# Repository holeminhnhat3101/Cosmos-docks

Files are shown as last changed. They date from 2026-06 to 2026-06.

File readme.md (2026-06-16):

# Cosmos Docks

Cosmos Docks is a custom 9-key macropad designed from scratch for Hack Club Stardance. It includes a custom PCB, a fully 3D-printable case, one rotary encoder, an OLED display, and SK6812MINI-E addressable RGB LEDs.

The design is built around the Seeed XIAO RP2040 and uses QMK firmware.

## Features

- 9 MX-style mechanical switches
- 1 EC11 rotary encoder
- 0.91 inch 128×32 I2C OLED display
- 13 SK6812MINI-E addressable RGB LEDs
- Seeed XIAO RP2040 microcontroller
- Custom 2-layer PCB designed in KiCad
- Fully 3D-printable top and bottom case
- QMK firmware with OLED, encoder, and RGB Matrix support
- M3 screws and heat-set inserts for case assembly

### PCB design preview
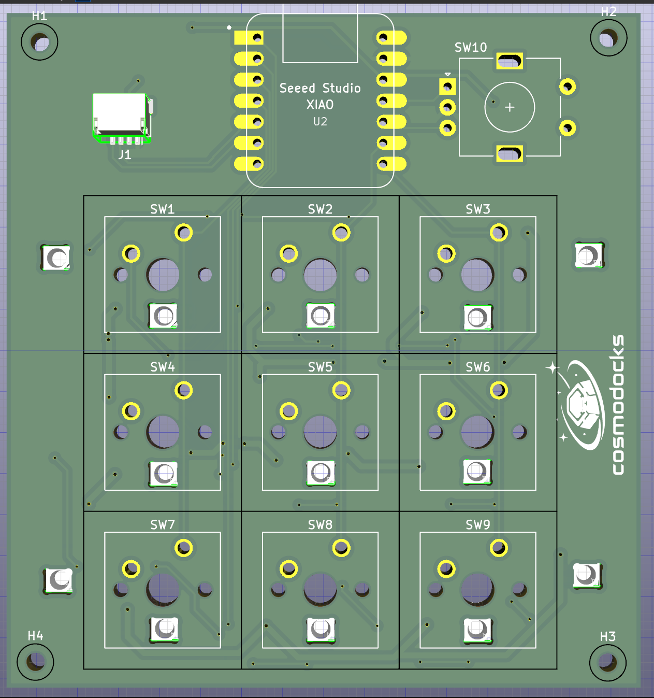
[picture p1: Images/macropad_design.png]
Design preview of Cosmos Docks


### PCB Layout
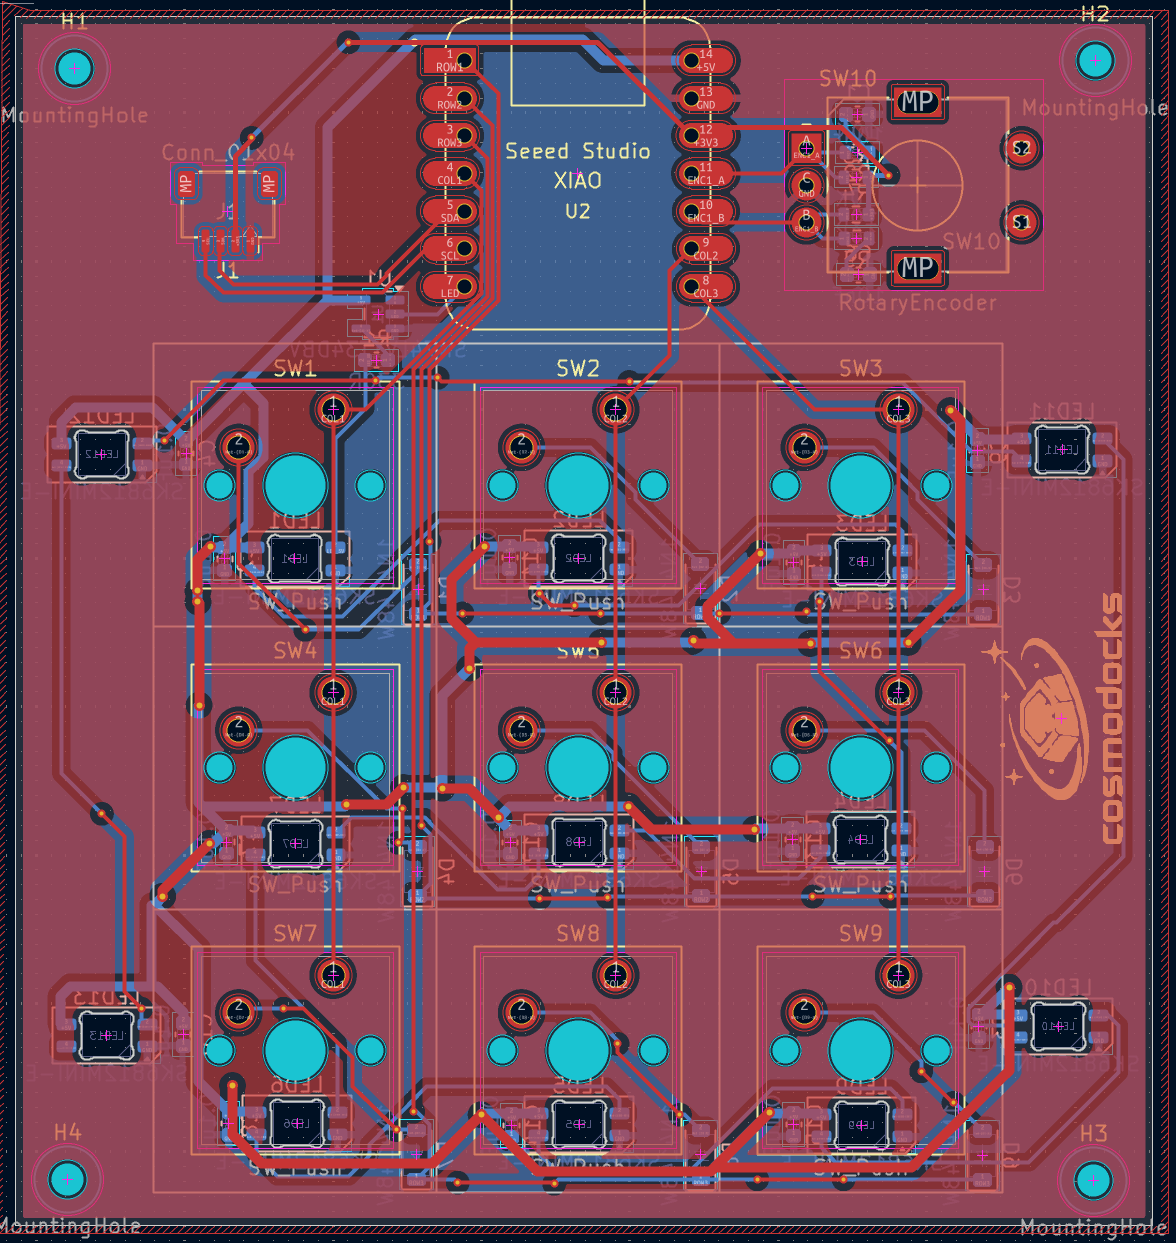
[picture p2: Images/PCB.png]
PCB layout of Cosmos Docks


### Schematic
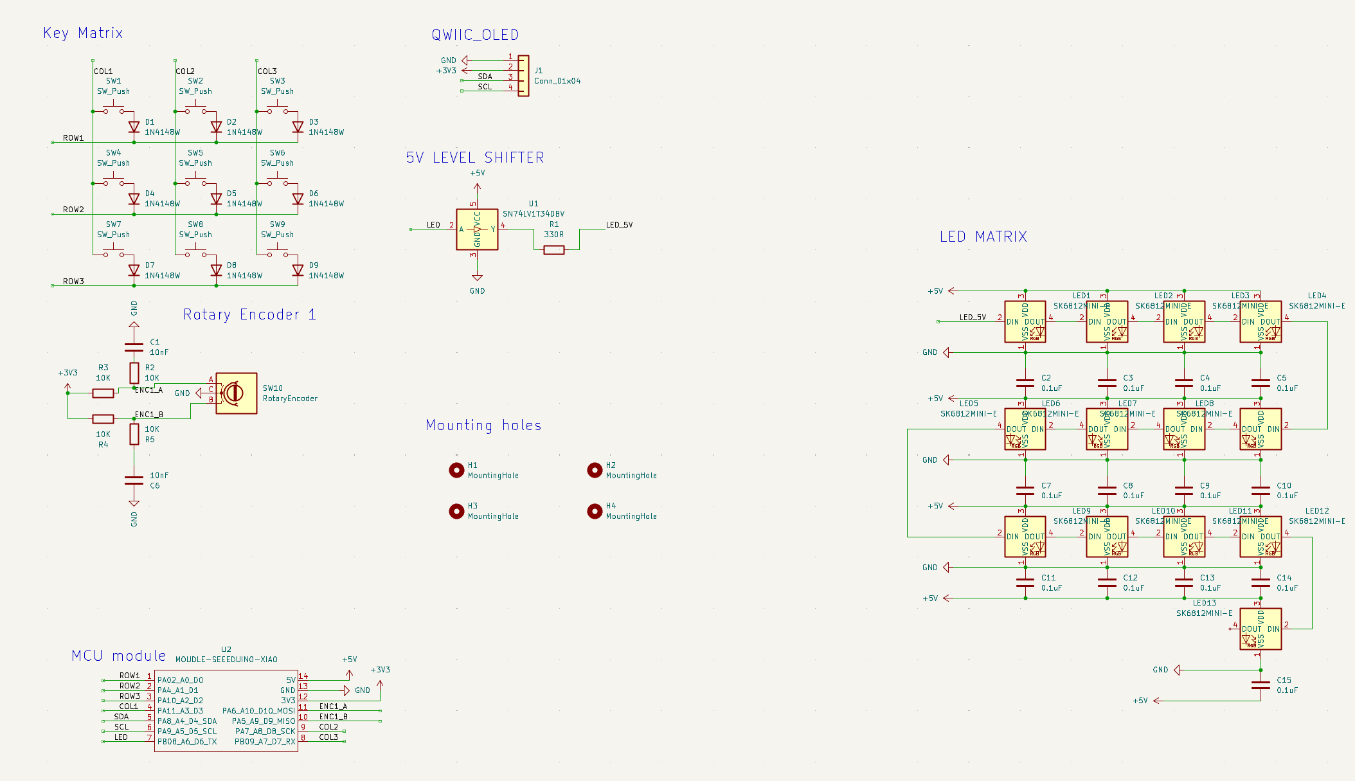
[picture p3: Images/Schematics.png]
Schematic of Cosmos Docks


### 3D Assembly
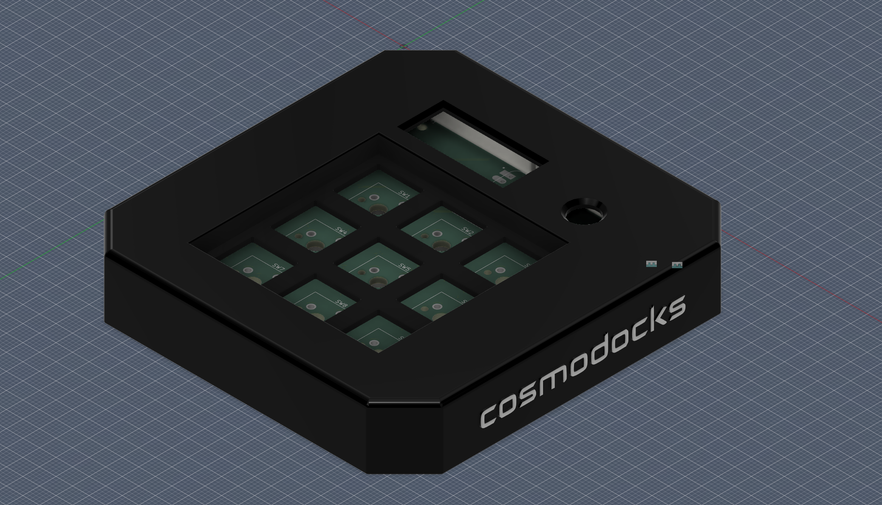
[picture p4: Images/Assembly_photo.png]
3D assembly photo of Cosmos Docks


## Bill of Materials

| Component | Quantity | Notes |
| --- | ---: | --- |
| Seeed XIAO RP2040 | 1 | Main microcontroller |
| MX-style mechanical switches | 9 | Main key switches |
| Blank DSA keycaps | 9 | Keycaps for the switches |
| 1N4148W SMD diodes | 9 | One diode per switch |
| EC11 rotary encoder | 1 | 20 mm D-shaft rotary encoder |
| 0.91 inch 128×32 I2C OLED display | 1 | OLED screen connected through I2C |
| JST-SH 4-pin connector | 1 | QWIIC/I2C OLED connector, SM04B-SRSS-TB, 1.00 mm pitch, horizontal |
| SK6812MINI-E RGB LEDs | 13 | Addressable RGB LEDs |
| 0.1 µF capacitors | 13 | One decoupling capacitor per RGB LED |
| 10 nF capacitors | 2 | Rotary encoder debounce/filtering capacitors |
| SN74LV1T34DBV level shifter | 1 | Shifts LED data from 3.3 V to 5 V |
| 330 Ω resistor | 1 | LED data line resistor |
| 10 kΩ resistors | 4 | Rotary encoder pull-up/pull-down resistors |
| M3×16 mm screws | 4 | Used to connect the top and bottom case |
| M3 heat-set inserts | 4 | Installed into the 3D-printed case |
| Custom PCB | 1 | 2-layer PCB designed in KiCad |
| 3D-printed top case | 1 | Top enclosure / switch plate |
| 3D-printed bottom case | 1 | Bottom enclosure |
| Soldering equipment | 1 | I don't have one |

## Firmware

The firmware is written using QMK. It includes support for:

- 3×3 key matrix
- Rotary encoder
- OLED display
- RGB Matrix lighting for SK6812MINI-E LEDs

The compiled firmware file is included in the production folder as:

firmware.uf2

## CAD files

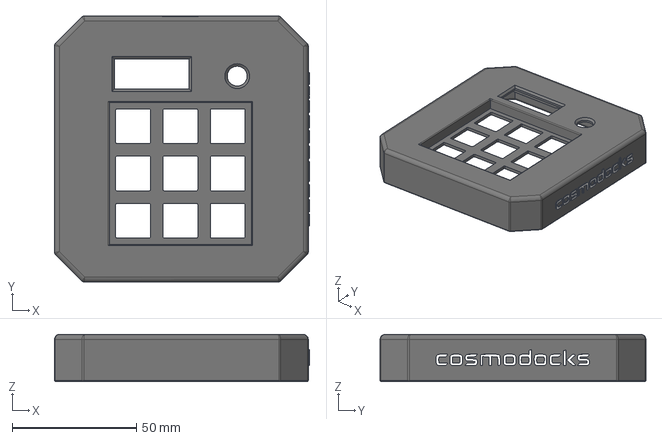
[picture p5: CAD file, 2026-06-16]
production/Top Case.step
102.7 x 107.1 x 19.0 mm

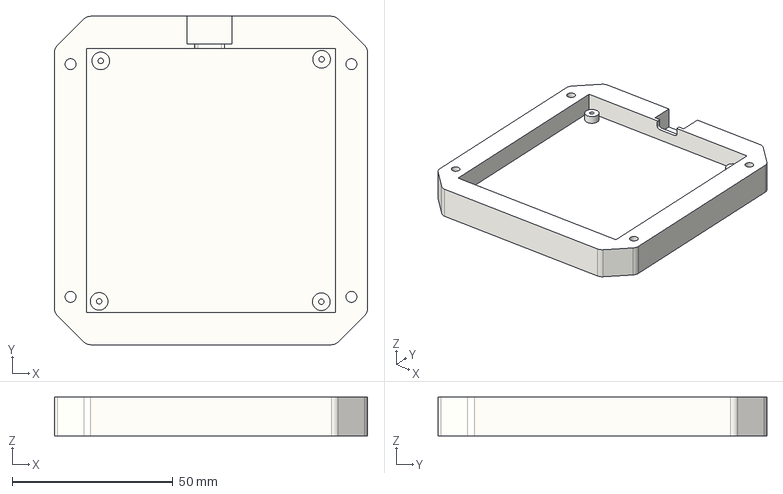
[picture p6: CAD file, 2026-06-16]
production/Bottom Case.step
97.4 x 102.2 x 12.1 mm

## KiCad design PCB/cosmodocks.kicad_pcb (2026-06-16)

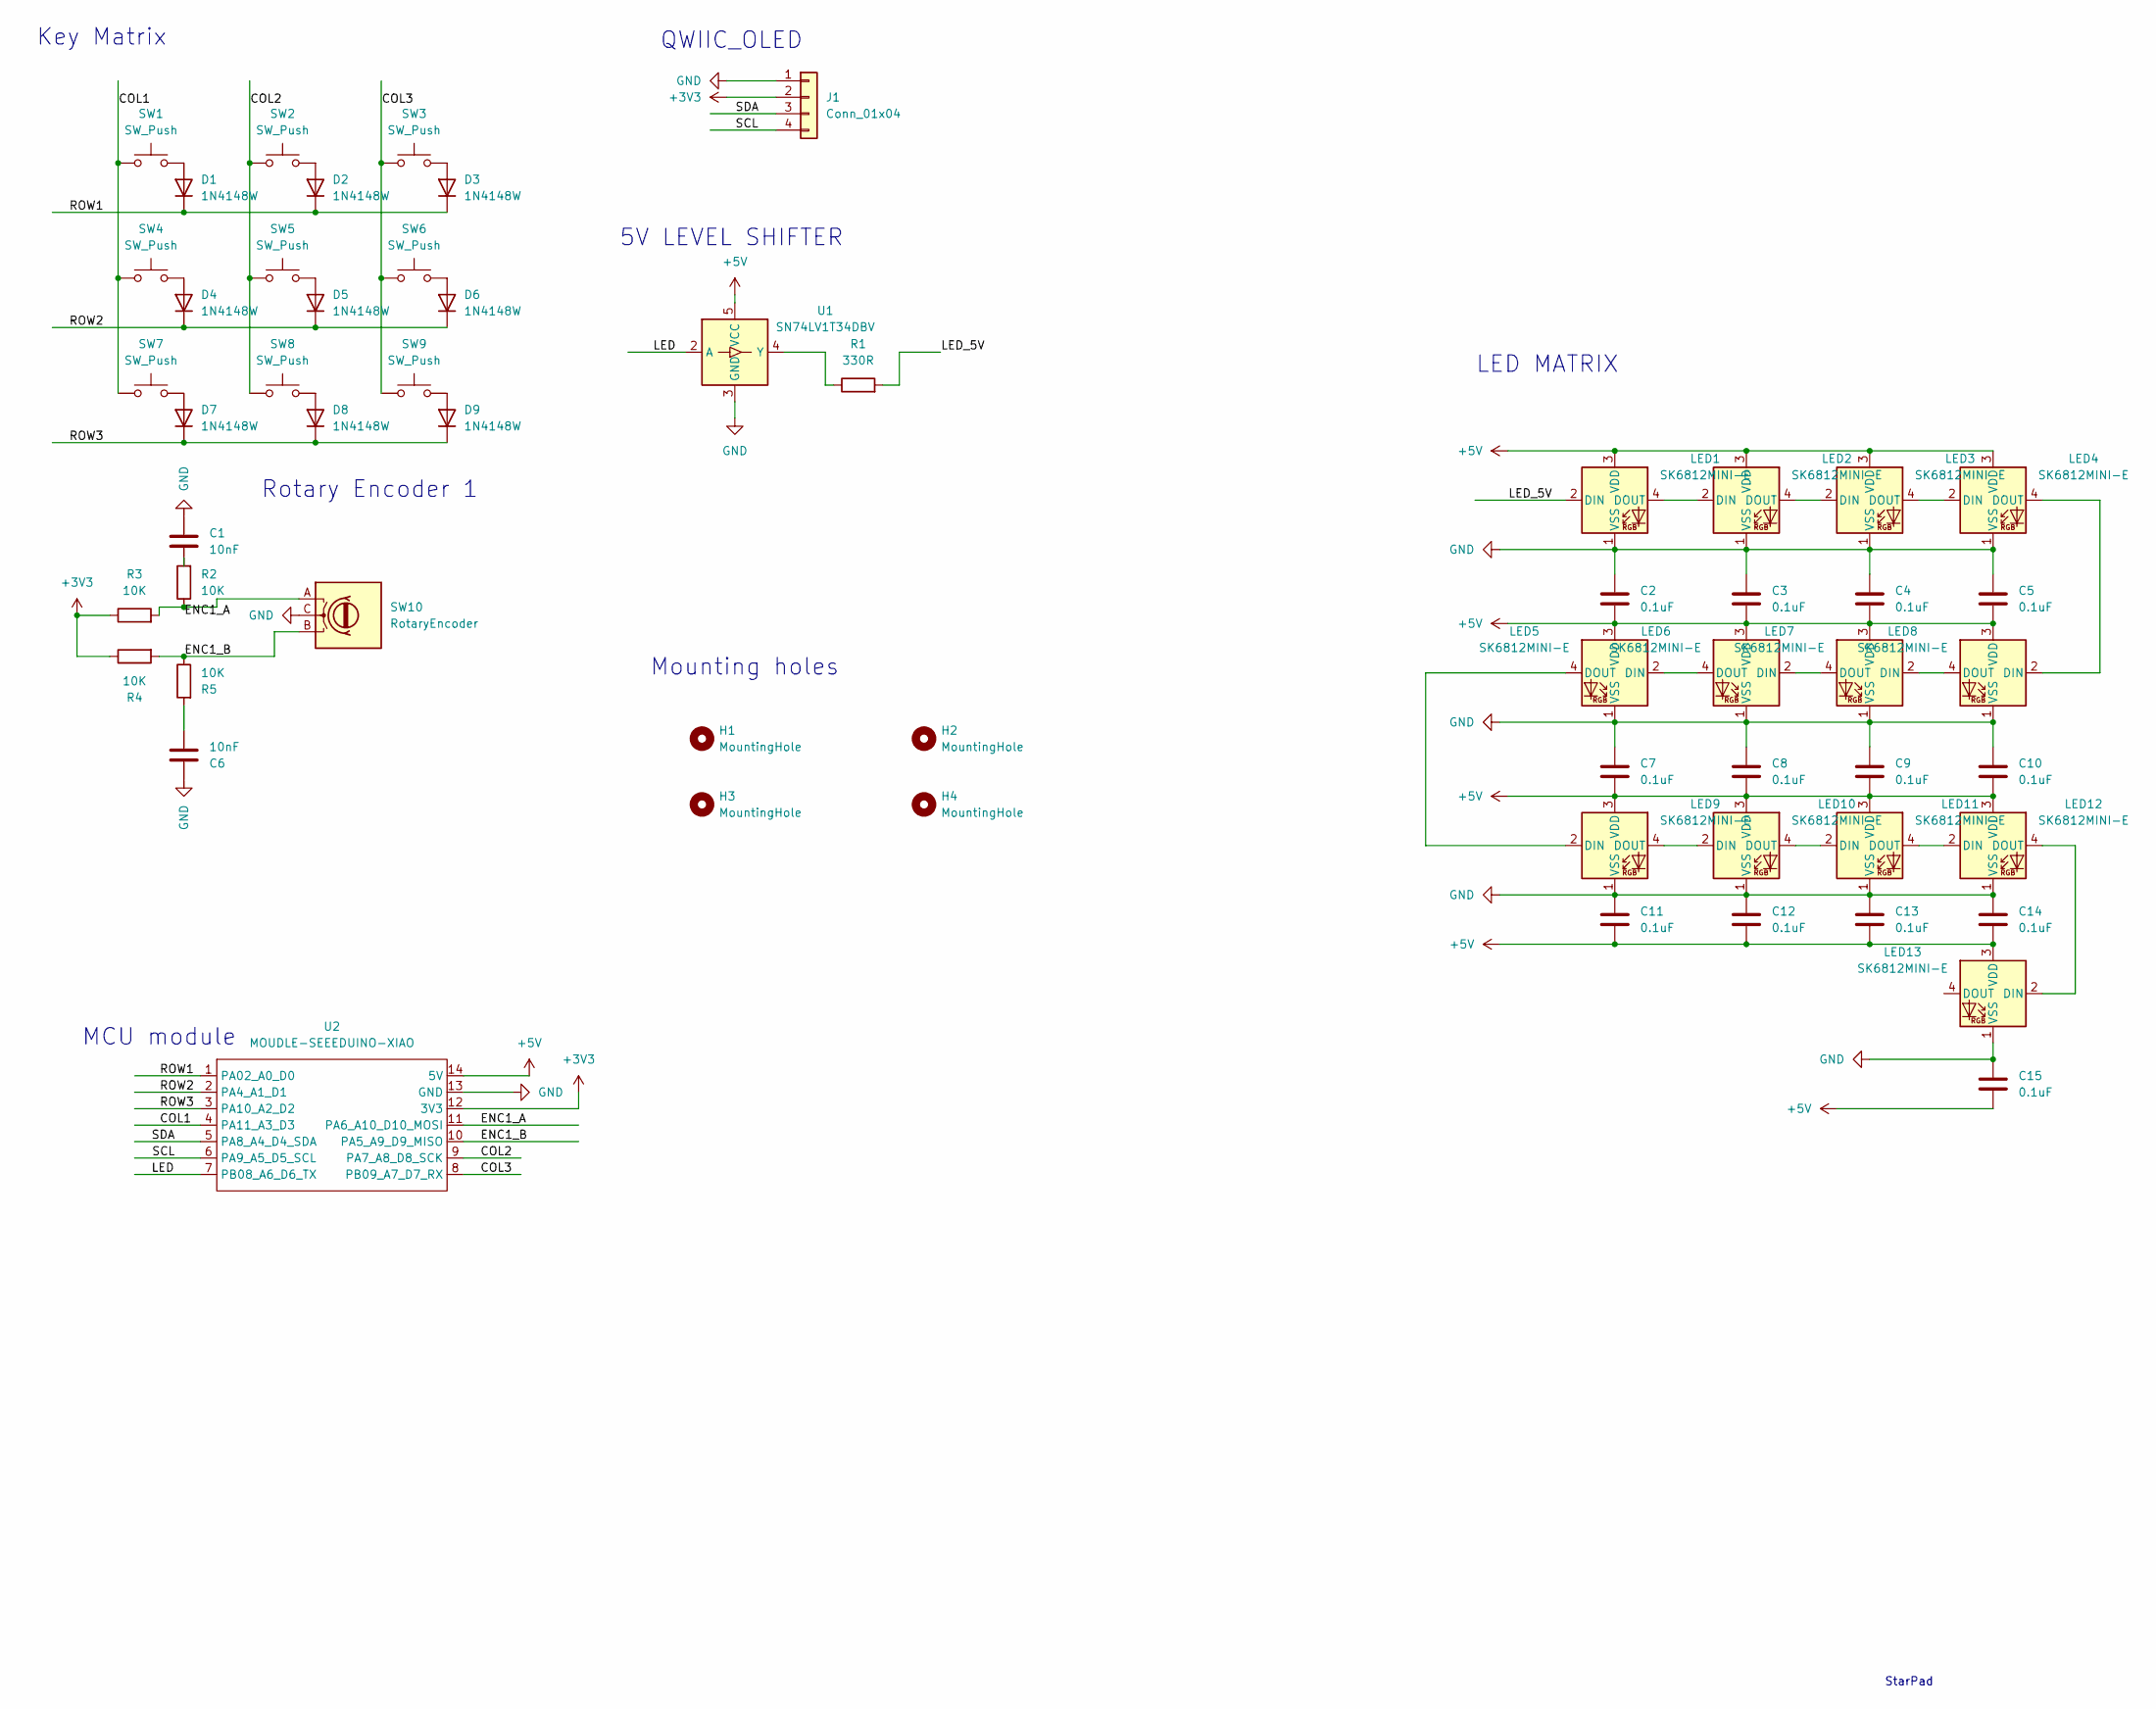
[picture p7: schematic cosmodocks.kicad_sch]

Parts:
C1, C6: 10nF; C_0603_1608Metric
C2, C3, C4, C5, C7, C8, C9, C10, C11, C12, C13, C14, C15: 0.1uF; C_0603_1608Metric
D1, D2, D3, D4, D5, D6, D7, D8, D9: 1N4148W; D_SOD-123
H1, H2, H3, H4: MountingHole; MountingHole_2.2mm_M2
J1: Conn_01x04; JST_SH_SM04B-SRSS-TB_1x04-1MP_P1.00mm_Horizontal
LED1, LED2, LED3, LED4, LED5, LED6, LED7, LED8, LED9, LED10, LED11, LED12, LED13: SK6812MINI-E; LED_SK6812MINI-E_3.2x2.8mm_P1.5mm_ReverseMount
R1: 330R; C_0603_1608Metric
R2, R3, R4, R5: 10K; R_0603_1608Metric
SW1, SW2, SW3, SW4, SW5, SW6, SW7, SW8, SW9: SW_Push; SW_Cherry_MX_1.00u_PCB
SW10: RotaryEncoder; RotaryEncoder_Alps_EC11E-Switch_Vertical_H20mm
U1: SN74LV1T34DBV; SOT-23-5
U2: MOUDLE-SEEEDUINO-XIAO; XIAO-Generic-Hybrid-14P-2.54-21X17.8MM

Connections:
+3V3: J1.2, R3.1, R4.1, U2.12 (3V3)
+5V: C2.2, C3.2, C4.2, C5.2, C7.2, C8.2, C9.2, C10.2, C11.2, C12.2, C13.2, C14.2, C15.2, LED1.3 (VDD), LED2.3 (VDD), LED3.3 (VDD), LED4.3 (VDD), LED5.3 (VDD), LED6.3 (VDD), LED7.3 (VDD), LED8.3 (VDD), LED9.3 (VDD), LED10.3 (VDD), LED11.3 (VDD), LED12.3 (VDD), LED13.3 (VDD), U1.5 (VCC), U2.14 (5V)
/COL1: SW1.1, SW4.1, SW7.1, U2.4 (PA11_A3_D3)
/COL2: SW2.1, SW5.1, SW8.1, U2.9 (PA7_A8_D8_SCK)
/COL3: SW3.1, SW6.1, SW9.1, U2.8 (PB09_A7_D7_RX)
/ENC1_A: R2.1, R3.2, SW10.A, U2.11 (PA6_A10_D10_MOSI)
/ENC1_B: R4.2, R5.1, SW10.B, U2.10 (PA5_A9_D9_MISO)
/LED: U1.2 (A), U2.7 (PB08_A6_D6_TX)
/LED_5V: LED1.2 (DIN), R1.2
/ROW1: D1.1 (K), D2.1 (K), D3.1 (K), U2.1 (PA02_A0_D0)
/ROW2: D4.1 (K), D5.1 (K), D6.1 (K), U2.2 (PA4_A1_D1)
/ROW3: D7.1 (K), D8.1 (K), D9.1 (K), U2.3 (PA10_A2_D2)
/SCL: J1.4, U2.6 (PA9_A5_D5_SCL)
/SDA: J1.3, U2.5 (PA8_A4_D4_SDA)
GND: C1.1, C2.1, C3.1, C4.1, C5.1, C6.1, C7.1, C8.1, C9.1, C10.1, C11.1, C12.1, C13.1, C14.1, C15.1, J1.1, LED1.1 (VSS), LED2.1 (VSS), LED3.1 (VSS), LED4.1 (VSS), LED5.1 (VSS), LED6.1 (VSS), LED7.1 (VSS), LED8.1 (VSS), LED9.1 (VSS), LED10.1 (VSS), LED11.1 (VSS), LED12.1 (VSS), LED13.1 (VSS), SW10.C, U1.3 (GND), U2.13 (GND)
unnamed: C1.2, R2.2
unnamed: C6.2, R5.2
unnamed: D1.2 (A), SW1.2
unnamed: D2.2 (A), SW2.2
unnamed: D3.2 (A), SW3.2
unnamed: D4.2 (A), SW4.2
unnamed: D5.2 (A), SW5.2
unnamed: D6.2 (A), SW6.2
unnamed: D7.2 (A), SW7.2
unnamed: D8.2 (A), SW8.2
unnamed: D9.2 (A), SW9.2
unnamed: LED1.4 (DOUT), LED2.2 (DIN)
unnamed: LED2.4 (DOUT), LED3.2 (DIN)
unnamed: LED3.4 (DOUT), LED4.2 (DIN)
unnamed: LED4.4 (DOUT), LED8.2 (DIN)
unnamed: LED5.2 (DIN), LED6.4 (DOUT)
unnamed: LED5.4 (DOUT), LED9.2 (DIN)
unnamed: LED6.2 (DIN), LED7.4 (DOUT)
unnamed: LED7.2 (DIN), LED8.4 (DOUT)
unnamed: LED9.4 (DOUT), LED10.2 (DIN)
unnamed: LED10.4 (DOUT), LED11.2 (DIN)
unnamed: LED11.4 (DOUT), LED12.2 (DIN)
unnamed: LED12.4 (DOUT), LED13.2 (DIN)
unnamed: R1.1, U1.4 (Y)

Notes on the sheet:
Mounting holes
QWIIC_OLED
StarPad
Rotary Encoder 1
LED MATRIX
MCU module
Key Matrix
5V LEVEL SHIFTER

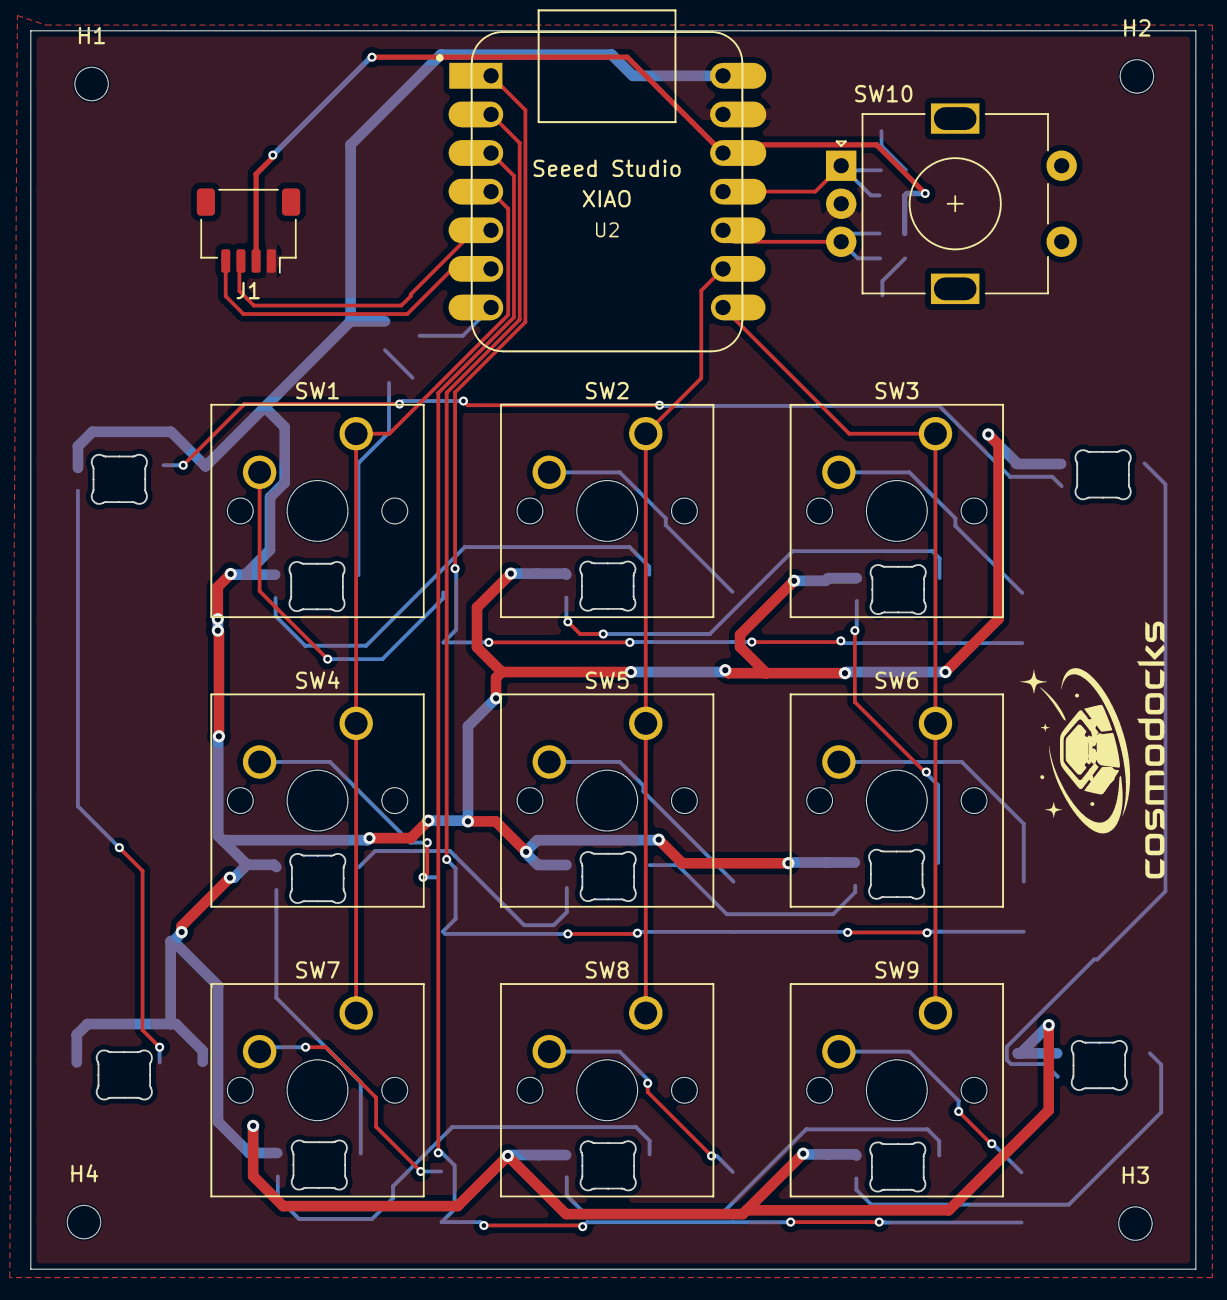
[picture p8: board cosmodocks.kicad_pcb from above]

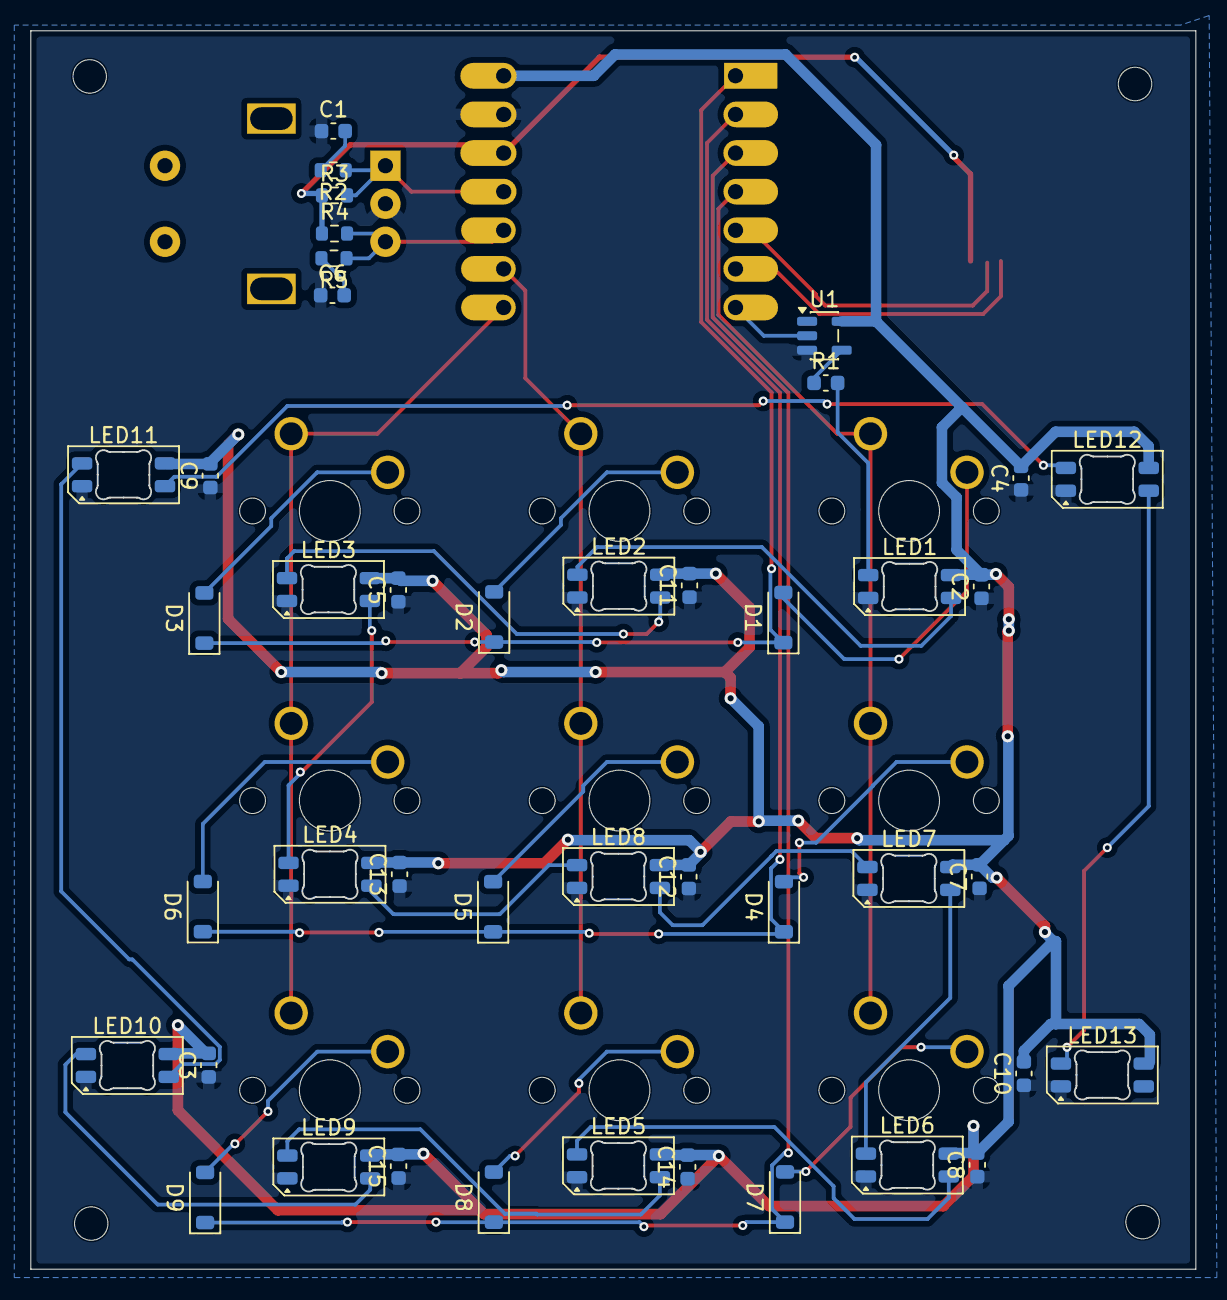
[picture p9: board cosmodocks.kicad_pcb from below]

Board: 2 copper layers, 76.6 x 81.5 mm, 59 parts (43 on the bottom side), 39 nets.

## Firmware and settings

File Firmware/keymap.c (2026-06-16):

// Copyright 2026 Ho Le Minh Nhat
// SPDX-License-Identifier: GPL-2.0-or-later

#include QMK_KEYBOARD_H

enum layers {
    _BASE,
    _FN
};

const uint16_t PROGMEM keymaps[][MATRIX_ROWS][MATRIX_COLS] = {
    /*
     * Base layer
     *
     * ┌─────┬─────┬─────┐
     * │  1  │  2  │  3  │
     * ├─────┼─────┼─────┤
     * │  4  │  5  │  6  │
     * ├─────┼─────┼─────┤
     * │  7  │  8  │ FN  │
     * └─────┴─────┴─────┘
     */
    [_BASE] = LAYOUT(
        KC_1,    KC_2,    KC_3,
        KC_4,    KC_5,    KC_6,
        KC_7,    KC_8,    MO(_FN)
    ),

    /*
     * Function layer
     *
     * ┌─────────┬─────────┬─────────┐
     * │ LED TOG │ LED MOD │ HUE +   │
     * ├─────────┼─────────┼─────────┤
     * │ SAT +   │ VAL +   │ MUTE    │
     * ├─────────┼─────────┼─────────┤
     * │ PREV    │ NEXT    │ TRNS    │
     * └─────────┴─────────┴─────────┘
     */
    [_FN] = LAYOUT(
        RM_TOGG, RM_NEXT, RM_HUEU,
        RM_SATU, RM_VALU, KC_MUTE,
        KC_MPRV, KC_MNXT, _______
    )
};

#ifdef ENCODER_MAP_ENABLE
const uint16_t PROGMEM encoder_map[][NUM_ENCODERS][NUM_DIRECTIONS] = {
    [_BASE] = { ENCODER_CCW_CW(KC_VOLD, KC_VOLU) },
    [_FN]   = { ENCODER_CCW_CW(RM_VALD, RM_VALU) }
};
#endif

#ifdef OLED_ENABLE
oled_rotation_t oled_init_user(oled_rotation_t rotation) {
    return OLED_ROTATION_0;
}

bool oled_task_user(void) {
    oled_write_ln_P(PSTR("Starcatcher"), false);
    oled_write_ln_P(PSTR("cosmos_docks"), false);
    oled_write_P(PSTR("Layer: "), false);

    switch (get_highest_layer(layer_state)) {
        case _BASE:
            oled_write_ln_P(PSTR("BASE"), false);
            break;
        case _FN:
            oled_write_ln_P(PSTR("FN"), false);
            break;
        default:
            oled_write_ln_P(PSTR("?"), false);
            break;
    }

    return false;
}
#endif
